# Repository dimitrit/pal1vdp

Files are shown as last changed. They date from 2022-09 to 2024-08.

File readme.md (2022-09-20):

# PAL-1 Sprite Colour Graphics Adapter

The PAL-1 Sprite Colour Graphics Adapter is an expansion board for the PAL-1 system<sup>1</sup>, 
based on the Texas Instruments TMS9918A Video Display Processor (VDP)<sup>2</sup> and was inspired 
by a Ciarcia's Circuit Cellar project<sup>3</sup>. 

The TMS9918A VDP was used in video systems to provide data display on raster scanned colour
television sets or monitors. The IC generates all necessary video, control, and synchronisation
signals and also controls the storage and retrieval of display data in its own dedicated screen 
memory. 

> **Note**  
> The TMS9918A VDP generates a 525-line NTSC encoded colour video signal. While the TMS9928A
> VDP, which is intended for use with PAL video systems, is functionally compatible with the
> TMS9918A, it is not pin-for-pin compatible. Thus it is **not possible** to use the TMS9928A 
> VDP in the PAL-1 Sprite Colour Graphics Adapter. Instead, users who do not have access to an 
> NTSC TV or monitor are recommended to use AV to HDMI or AV to VGA converters as appropriate.
> Such converters are widely available from the usual e-commerce and auction web sites. 

## Acknowledgements
The SRAM circuitry is based on work by Tom LeMense and Dan Werner<sup>4,5</sup>.  
PAL-1 and the PAL-1 logo used with kind permission of Liu Ganning.

## References
1. Liu Ganning, ‘PAL-1 Microcomputer User Manual’, 2020 <http://pal.aibs.ws/assets/PAL_en.pdf> [accessed 21 July 2022].
2. ‘9900 TMS9918A/TMS9928A/TMS9929A Video Display Processors’ (Texas Instruments Incorporated, 1982) <https://web.archive.org/web/20180717212934/https://emu-docs.org/VDP%20TMS9918/Datasheets/TMS9918.pdf> [accessed 17 September 2022].
3. Steve Ciarcia, ‘High-Resolution Sprite-Oriented Color Graphics’, Byte, 7.8 (1982), 57–80.
4. Tom LeMense, ‘SRAM Replacement for TMS99x8 VRAM’, 2010 <https://retrobrewcomputers.org/n8vem-pbwiki-archive/0/35845334/48860720/33053543/SRAM%20Replacement%20for%20TMS99x8%20VRAM.pdf> [accessed 17 September 2022].
5. Tom LeMense and Dan Werner, ‘Video Display Interface Board’, RetroBrew Computers Wiki, 2021 <https://www.retrobrewcomputers.org/doku.php?id=boards:ecb:scg:start> [accessed 17 September 2022].

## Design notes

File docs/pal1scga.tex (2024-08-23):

\documentclass[a4paper,11pt,twoside,openright]{report}
\usepackage{standalone}
\usepackage[lmargin=142pt,rmargin=95pt,tmargin=127pt,bmargin=123pt]{geometry}
\usepackage[titleformat=italic,commabeforerest,citefull=first,oxford,super,dotafter=bibentry,see,bibformat=ibidem,human]{jurabib}
\usepackage{csvsimple}
\usepackage{graphicx}
\usepackage{caption}
\usepackage{subcaption}
\usepackage[table]{xcolor}
\usepackage[online,flushleft]{threeparttable}
\usepackage{multirow}
\usepackage{makecell}
\usepackage[super]{nth}
\usepackage[most]{tcolorbox}
\usepackage{listings}
\usepackage{float}
\usepackage{enumitem}
\usepackage{fdsymbol}
\usepackage{awesomebox}
\usepackage{titlesec}
\usepackage[hidelinks]{hyperref}
%\usepackage{inconsolata}
\usepackage{tikz}
\usepackage{tkz-euclide}
\usetikzlibrary{intersections,shapes.arrows,arrows.meta}
\lstset{aboveskip=18pt,belowskip=18pt}
\tcbset{colframe=blue!50!black,colback=blue!20}
\hypersetup{
%   colorlinks=false,
%    linkcolor=blue,
%    filecolor=magenta,
%    urlcolor=cyan,
    pdftitle={PAL-1 Sprite Colour Graphics Adapter},
    pdfpagemode=UseThumbs,
    pdfauthor={Plastic Objects Limited}
}
\renewcommand{\arraystretch}{1.1}
\renewcommand*{\biburlprefix}{\jblangle{}}
\renewcommand*{\bibbudcsep}{~}
\renewcommand\bibname{References}
\AddTo\bibsenglish{\renewcommand*{\urldatecomment}{accessed }}
\titleformat{\chapter}{\normalfont\huge}{\thechapter.}{20pt}{\huge\it}
\makeatletter
\newcommand{\code}{\texttt}
\newcommand\frontmatter{
  \cleardoublepage
  \pagenumbering{roman}}
\newcommand\mainmatter{
  \cleardoublepage
  \pagenumbering{arabic}}
\newcommand\encircle[1]{
  \tikz[baseline=(X.base)]
  \node (X) [draw, shape=circle, inner sep=0] {\strut #1};}
\title{PAL-1 Sprite Colour Graphics Adapter}
\author{Plastic Objects Limited}
\date{}
\begin{document}
\frontmatter
\begin{titlepage}
\begin{figure}[t]
\centering
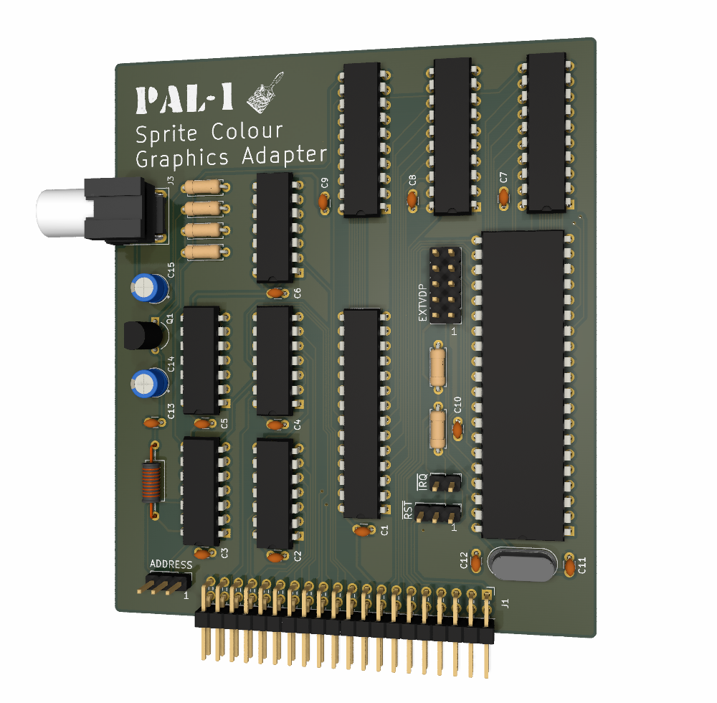
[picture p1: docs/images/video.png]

\end{figure}
\maketitle
\end{titlepage}
\clearpage
\noindent Published by \textbf{Plastic Objects Limited} \\
Beccles, UK

\bigskip
\noindent September 2024
\vfill
{\noindent\Large\textbf{Disclaimer}}
\vskip 6pt
Every effort has been made to ensure the accuracy of the information contained in this document. The information presented within is accurate at the time of publication. Whilst every effort is made to provide accurate information, no warranty or fitness is provided or implied, and the authors and publishers shall have neither liability nor responsibility to any person or entity with respect to any loss or damages arising from its use.

All trademarks, logos and brand names are the property of their respective owners. All company, product and service names mentioned in this document are for identification purposes only. Use of these names, trademarks and brands does not imply endorsement.

\thanks{PAL-1 and the PAL-1 logo used with kind permission by Liu Ganning.}
\clearpage
\tableofcontents
\listoffigures
\cleardoublepage
\chapter*{Introduction}
\addcontentsline{toc}{chapter}{Introduction}
The PAL-1 Sprite Colour Graphics Adapter (SCGA) is an expansion module for the PAL\nobreakdash-1 system\cite{ganning1} based on the Texas Instruments TMS9918A Video Display Processor (VDP)\cite{texas1}. The TMS9918A VDP was used in video systems to provide data display on raster scanned colour television sets or monitors. The IC generates all necessary video, control, and synchronisation signals and also controls the storage and retrieval of display data in its own dedicated screen memory.

\awesomebox[blue]{2pt}{\faInfoCircle}{blue}{The TMS9918A VDP generates a 525-line NTSC encoded colour video signal. While the TMS9928A VDP, which is intended for use with PAL video systems, is functionally compatible with the TMS9918A, it is not pin-for-pin compatible. Thus it is not possible to use the TMS9928A VDP in the PAL-1 Sprite Colour Graphics Adapter. Instead, users who do not have access to an NTSC TV or monitor are recommended to use AV to HDMI or AV to VGA converters as appropriate. Such converters are widely available from the usual e-commerce and auction web sites.}

This expansion module was inspired by a Ciarcia's Circuit Cellar project for a `High-Resolution Sprite-Oriented Color Graphics' expansion card for the Apple II computer, published in BYTE magazine.\cite[pp. 57--80]{byte1} The design for the PAL-1 SCGA also incorporates Static RAM (SRAM) circuitry based on work by Tom LeMense and Dan Werner.\cite{lemense1}\textsuperscript{,}\cite{werner1}

\section*{Overview of the TMS9918A VDP}
The TMS9918A VDP contains all necessary circuitry to generate a video display with up to 16 colours and a maximum resolution of 256 x 192 pixels. Additionally, the VDP supports the display of up to 32 sprites. The image displayed on the screen can best be envisioned as a number of display planes sandwiched together, where each plane has a different priority. For an entity on a specific plane to show through, all planes with higher priorities must be transparent at that point (see Figure \ref{fig:planes}).

\begin{figure}[h!]
	\centering
    \begin{subfigure}[b]{0.4\textwidth}
		\centering
			\scalebox{0.1}{
			\begin{tikzpicture}[font=\sffamily]
				\foreach \p [
				count=\q,
				evaluate=\q as \r using 9-\q
				] in {0,1,2,31,{Pattern plane (text \& graphics)},{Backdrop (solid colour)},{External VDP input},{Black plane}} {
					\def\c{white}
					\ifnumequal{\q}{1}{\def\c{black}}{}
					\ifnumequal{\q}{3}{\def\c{gray!40}}{}
					\draw [line width=4,fill=\c] (\r*6+2.25,\r*5+5) rectangle ++(16,12);
					\draw (\q*6+18.5, \q*5+6) node[anchor=west,scale=8]{\p};
				}
				\foreach \q in {1,2,3} {
					\draw[fill=black] (\q*1.75+38.5,\q+20.5) circle (.25);
				}
				\draw (34,39) node[anchor=west,scale=6]{Hello world};
				\draw[fill=gray!30,line width=2] (9,11) -- ++(4,0) -- ++(-2,4) -- cycle;
				\begin{scope}[fill=white]
					\fill[clip] (24.25,18) rectangle ++(4,4);
					\draw[line width=2] (25.25,20) circle (2);
				\end{scope}
				\draw[fill=gray!80,line width=2] (31.25,21) rectangle ++(4,4);
				\draw [decorate,decoration={brace,amplitude=26pt,mirror,raise=8ex},line width=4]
				(46,10) -- ++(0,18) node[midway,xshift=30em,scale=8]{Sprite planes};

			\end{tikzpicture}
		}
		\caption{Individual display planes.}
	\end{subfigure}\hfill
    \begin{subfigure}[b]{0.4\textwidth}
		\centering
		\scalebox{0.1}{
			\begin{tikzpicture}[font=\sffamily]
				\draw[line width=4] (-12,60) -- ++(-8,-12) -- ++(-4,8);
				\draw[fill=black!80] (-20,43) circle (6);
				\draw[line width=4,fill=white,rounded corners=0.2cm] (-32,28) rectangle ++(28,20) {};
				\draw[line width=8,rounded corners=1cm,fill=gray!40] (-30,30) rectangle ++(20, 16) {};
				\draw[fill=black] (-12.1,59.9) circle (.3);
				\draw[fill=black] (-24,56) circle (.3);
				\draw[fill=black!60,line width=4] (-7,41) circle (1);
				\draw[fill=black!60,line width=4] (-7,44) circle (1);
				\begin{scope}
					\draw[clip] (-7,41) circle (1);
					\draw[line width=8] (-7.5,40) -- (-6.5,42);
				\end{scope}
				\begin{scope}
					\draw[clip] (-7,44) circle (1);
					\draw[line width=8] (-6.8,43) -- (-7.2,45);
				\end{scope}
				\draw[fill=black!60,line width=2] (-9,31) rectangle ++(4,6);
				\foreach \q in {1, ..., 5}{
					\draw[line width=8, color=black!40] (-8.5,\q+31) -- ++(3,0);
				}
				\draw [color=white,fill=white] (-28,32) rectangle ++(16,12);
				\draw (-26,41) node[anchor=west,scale=6]{Hello world};
				\draw[fill=gray!30,line width=2] (-27,33) -- ++(4,0) -- ++(-2,4) -- cycle;
				\draw[fill=gray!80,line width=2] (-17,33) rectangle ++(4,4);
				\draw[fill=white,line width=2] (-17,37) circle (2);

				\draw[line width=2] (-17,30.5) -- ++(3,-5) -- ++(-1,0) -- ++(3,-5)
				node[scale=8,yshift=-.6em]{Backdrop};
			\end{tikzpicture}
		}
		\caption{Image shown on screen.}
	\end{subfigure}
    \caption[TMS9918A VDP display planes]{TMS9918A VDP overlapping display planes.}
	\label{fig:planes}
\end{figure}

In descending priority order, the display planes are made up of 32 \textit{Sprite Planes}, each of which may contain a single sprite. Below these sprite planes is the \textit{Pattern Plane}, which is used for the display of textual and graphics images. Below this is the \textit{Backdrop Plane}, which provides a single colour border around all other planes and sets the default colour for the active display area. Finally, with the lowest priority is the \textit{External Video Plane}, which displays a video image from a compatible external source (see also appendix \ref{sec:ttlpins}).

The VDP supports four video colour display modes that determine the appearance of the Pattern Plane. In both graphics modes, \textit{Graphics 1} and \textit{Graphics 2}, the pattern plane is split into groups of 8x8 pixels, referred to as pattern positions. Graphics and images using multiple colours may be created by defining unique patterns for each pattern position. In \textit{Text} mode, the Pattern Plane is split into groups of 6x8 pixels, resulting in 40x24 text positions on the screen. Sprites are not displayed in \textit{Text} mode and only two colours are allowed. Finally, in \textit{Multicolor} mode, the screen is split into a grid of 64x48 positions, each of which is 4x4 pixels. In this mode, each position may have a unique colour.

The \textit{Sprite Planes} are used for the display of up to 32 sprites in the \textit{Multicolor} and \textit{Graphics} modes. Sprites are automatically transparent in \textit{Text} mode and thus cannot be used in this mode. Each sprite covers a 8x8, 16x16 or 32x32 pixel area and may be positioned anywhere on its plane. Any part of the plane not covered by the sprite is transparent, as may be all or part of a sprite.

The VDP registers define the base addresses for several sub-blocks within Video RAM (VRAM). The sub-blocks form \textit{tables} which are used to define sprites and produce the desired text or images on the screen. Before use, the contents of these tables must be initialised by applications running on the PAL-1. Displaying text, drawing images and moving sprites across the screen can be achieved by choosing the relevant register parameters and changing the pointers.

\mainmatter
\chapter{Getting Started}
\section*{Board assembly}
Before assembling your PAL-1 Sprite Colour Graphics Adapter board check the package contents against the Bill of Materials on page \pageref{sec:bom}, and contact your distributor as soon as possible if any items are missing.

No specialist tools are required for assembling the board, though care must be taken when handling ESD sensitive components, especially the ICs. Before inserting the ICs into their sockets, check the board for dry joints and solder bridges. Also be sure to pay special attention to the orientation of the ICs, ensuring pin 1 of each IC is correctly aligned. Refer to the board layout on page \pageref{fig:layout} for the orientation of ICs, diodes and electrolytic capacitors.

\section*{Installation and configuration}
\label{sec:configuration}

Because of its width, the PAL-1 Sprite Colour Graphics Adapter cannot be installed in all slots of the PAL-1 Motherboard.\cite{ganning2} Rather, it must be installed in any of slots 4, 5, or 6. Alternatively, it may be directly connected to the PAL-1 using a 40-pin IDC cable.

\awesomebox[red]{2pt}{\faHandPaper}{red}{To prevent damage to your system, \textit{always} power off your PAL-1 before installing or removing the PAL-1 Sprite Colour Graphics Adapter board. Ensure that the pins are correctly aligned when inserting the board into the PAL-1 motherboard or when directly connecting it to the PAL-1 expansion port using an IDC cable.}

\subsection*{Data and register addresses}
The TMS9918A VDP has an 8-bit data bus, which is memory mapped on the PAL-1 system at addresses determined by the position of the \textsf{ADDRESS} jumper, as shown in Table \ref{tab:address}. Up to two PAL-1 Sprite Colour Graphics Adapters can be installed in one system by assigning each adapter unique data and register addresses.

\begin{table}
	\centering
	\sf
	\renewcommand{\arraystretch}{1.1}
	\begin{tabular}{@{\extracolsep{4pt}}ccc@{}}
		\hline
		\textbf{Pins} & \textbf{VDP data} & \textbf{VDP register} \\
		\hline
		\textbf{1 -- 2} & \$16EC & \$16ED \\
		\textbf{2 -- 3} & \$16EE & \$16EF \\
		\hline
	\end{tabular}
	\caption{\textsf{ADDRESS} jumper settings.}
	\label{tab:address}
\end{table}
\subsection*{Option jumpers}
The PAL-1 Sprite Colour Graphics Adapter has two option jumpers to configure its behaviour:

\begin{itemize}
	\item[$\overline{\mbox{RST}}$]
	\begin{description}
		\item[1 -- 2] Disables TMS9918A $\overline{\mbox{RESET}}$/SYNC using pull-up resistor $R1$.
		\item[2 -- 3] Connects the TMS9918A  $\overline{\mbox{RESET}}$/SYNC line with the $\overline{\mbox{RESET}}$ line of the PAL-1 MOS6502 CPU, ensuring it is used as a reset signal on the VDP.
		\item[No jumper] This jumper \textit{must} be removed when using the \textsf{EXTVDP} external video pin header.
	\end{description}
	\item[$\overline{\mbox{INT}}$] Enable CPU interrupts. If enabled, interrupts are raised each time a frame is completed, while the beam is tracing up to the upper left corner of the screen. This occurs every $1/60$\textsuperscript{th} of a second (approximately).
\end{itemize}

\chapter{Sample Code}

Programming the PAL-1 Sprite Colour Graphics Adapter simply requires the ability to write to and read from the memory mapped data and register addresses. Many programming languages provide statements to achieve this, including the \code{POKE} and \code{PEEK} statements in BASIC, and \code{C!} and \code{C@} in Forth.

Note that the examples included below use the default SCGA data and register addresses (\$16EC, $5868_{10}$ and \$16ED, $5869_{10}$).  Further examples may be found on Github at \url{https://github.com/dimitrit/pal1vdp}.

\subsection*{BASIC}

\textsf{TODO!}

%\lstinputlisting[basicstyle=\footnotesize\ttfamily,caption={BASIC example},captionpos=b,
%	language={[Visual]Basic},label={lst:sample1},frame=single]{../src/KNIGHT.BAS}

\subsection*{6502 assembly language}

The assembly language example is taken from the `\textit{High-Resolution Sprite-Oriented Color Graphics}' article in the August 1982 issue of BYTE magazine.\cite[pp. 57--80]{byte1} The code has been modified where required to allow it to run on the PAL-1.

\begin{figure}[h!]
\centering
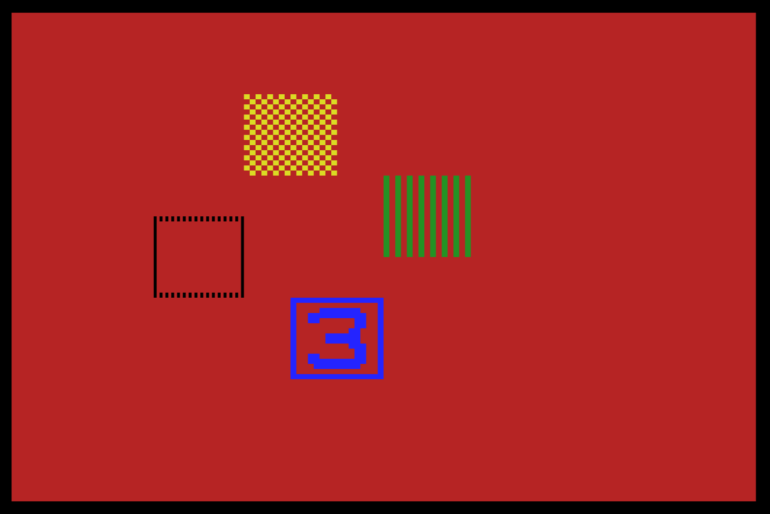
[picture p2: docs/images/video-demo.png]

\caption[Assembly language Video Demo showing sprites]{6502 Assembly language \textit{Video Demo} showing four sprites.}
\label{fig:asmdemo}
\end{figure}

The program starts by initialising the eight VDP registers and clearing the VRAM. In this example the 9918A is set to the following operating specifications: Graphics II mode, external video input disabled, and 16 x 16 pixel sprites, with selectable magnification to twice their normal size (32 x 32 pixels) under keyboard control. When the program starts, four different sprites are displayed, as shown in Figure \ref{fig:asmdemo}. The display can be changed as follows. When you press the \textsf{GO} key, the sprites' position coordinates are incremented and the sprites move. Pressing the \textsf{0} key and then a hexadecimal digit \textsf{1} through \textsf{F} will set one of the fifteen background colours or transparency. Pressing the \textsf{AD} or \textsf{DA} keys will vary the size of the sprites between 16 x 16 and 32 x 32 pixels.

\lstinputlisting[basicstyle=\footnotesize\ttfamily,caption={Ciarcia's Circuit Cellar Video Demo},
	captionpos=b,language={[Motorola68k]Assembler},
	label={lst:sample2},frame=single]{../src/ciarcia.a65}

\appendix

\chapter{Connector Pin Outs}
\label{sec:connectors}

\subsection*{External Video Pin Header (\textsf{EXTVDP})}
\label{sec:ttlpins}
The PAL-1 Sprite Colour Graphics Adapter (SCGA) external video pin header (\textsf{EXTVDP}) can be used to connect a compatible external video source. Alternatively, it allows the SCGA to be used as the source for other systems.\cite[pp. 3.7--3.8]{texas1}

Note that the pins of this header are numbered `odd-even' with pin \textsf{1} clearly marked on the PCB, as shown in figures \ref{fig:pinheader} and \ref{fig:layout}. \textbf{Be sure to check the TTL voltage levels and signals before connecting any external systems as incorrect voltages and/or incompatible signals may result in permanent damage to your PAL-1 Sprite Colour Graphics Adapter.}

\begin{figure}[h!]
	\centering
    \begin{minipage}[b]{\linewidth}
	    \centering
		\scalebox{0.1}{
			\begin{tikzpicture}[font=\sffamily]
				\draw (3,5.5) node[scale=12, rotate=-90,color=gray]{1};
				\draw (5.5,17) node[scale=12,anchor=west,color=gray]{EXTVDP};
				\draw [line width=8] (6,4) -- ++(0,9);
				\draw [line width=8] (6,13)
				\foreach \q in {1, ..., 5} { -- ++(1,1) -- ++(4,0) -- ++(1,-1) } -- ++(0,-9)
				\foreach \q in {5, ..., 1} {	-- ++(-1,-1) -- ++(-4,0) -- ++(-1,1) } -- cycle;
				\foreach \q [
						evaluate=\q as \odd using int(\q*2-1),
						evaluate=\q as \even using int(\q*2)
				] in {5, ..., 1} {
					\draw [fill=black] (\q*6+2.25,5.5) rectangle ++(1.5,1.5);
					\draw [fill=black] (\q*6+2.25,10) rectangle ++(1.5,1.5);

					\draw (3+\q*6, 16.5) node[scale=8]{\even};
					\draw (3+\q*6, 0.5) node[scale=8]{\odd};
				}
			\end{tikzpicture}
		}
		\captionof{figure}[External video pin header]{\textsf{EXTVDP} external video pin header.}
		\label{fig:pinheader}
	\end{minipage}
	~\par\bigskip
    \begin{minipage}[b]{\linewidth}
			\renewcommand{\arraystretch}{1.1}
			\centering
			\begin{tabular}{@{\extracolsep{4pt}}clp{80mm}@{}}
				\hline
				Pin & Signal & Description \\
				\cline{1-3}
				1 & GND & Ground  \\
				2 & VCC & +5V Supply Voltage \\
				3 & GND & Ground  \\
				4 & COMVID & Composite Video Output \\
				5 & GROMCLK & VDP Output Clock $= XTAL/24$ \\
				6 & COMVID & Composite Video Output \\
				7 & EXTVDP & External Video (VDP) Input \\
				8 & CPUCLK &  VDP Colour Burst Frequency Clock \\
				9 &  $\overline{\mbox{RESET}}$/SYNC & This is a tri-level input pin. When it is below 0.8 volts, $\overline{\mbox{RESET}}$/SYNC initialises the VDP. When it is above 9 volts $\overline{\mbox{RESET}}$/SYNC is the synchronising input for external video. \\
				10 & COMVID\textsubscript{r} & Unconditioned Composite Video Output of the TMS9918A VDP. \\
				\hline
			\end{tabular}

		\captionof{table}[External video pin header]{\textsf{EXTVDP} external video pin header.}
		\label{tab:ttlpins}
	\end{minipage}
\end{figure}

\chapter{Schematic}
\label{sec:schematic}

\begin{figure}[h!]
	\centering
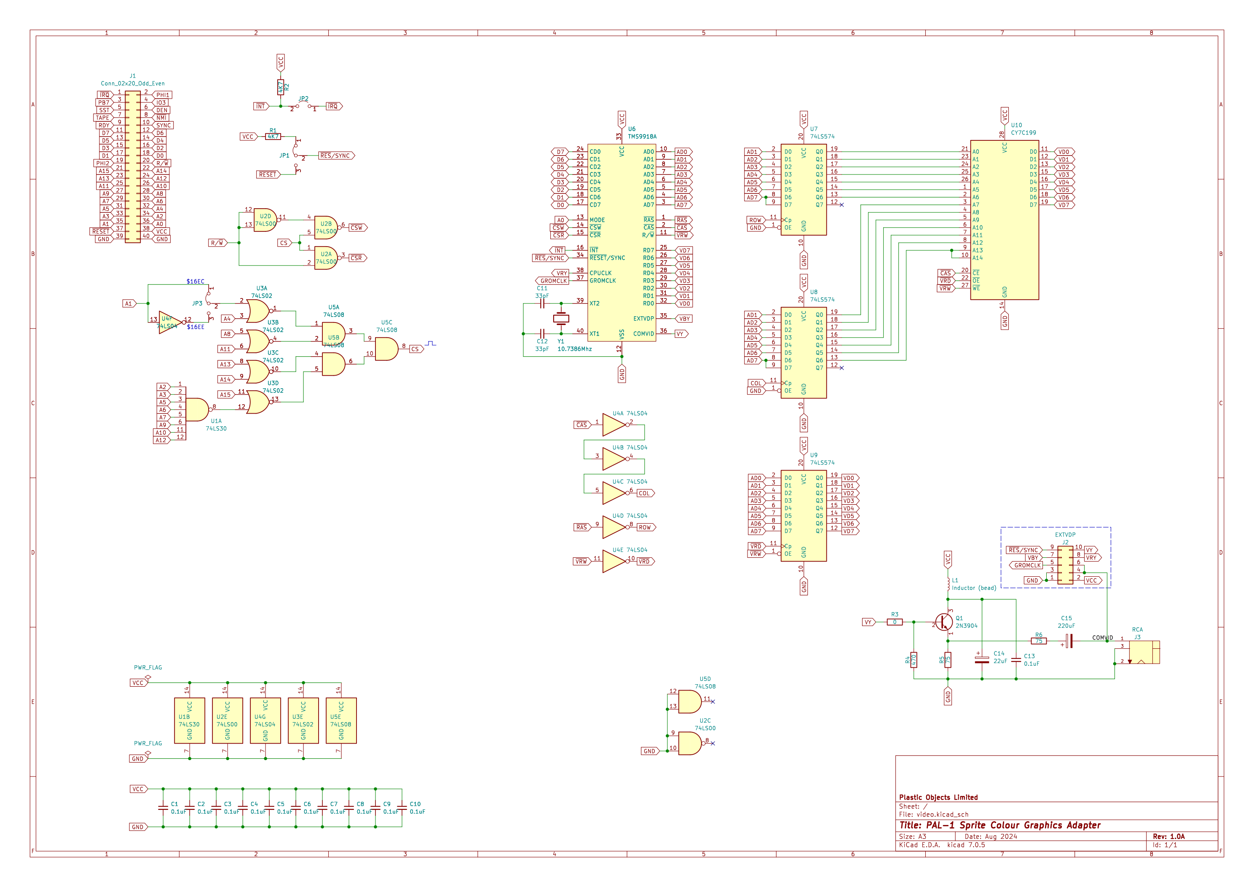
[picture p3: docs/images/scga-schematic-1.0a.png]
	
	\caption[Sprite Colour Graphics Adapter schematic]{PAL-1 Sprite Colour Graphics Adapter schematic.}
	\label{fig:layout}
\end{figure}

\chapter{Board layout}
\begin{figure}[h!]
\centering
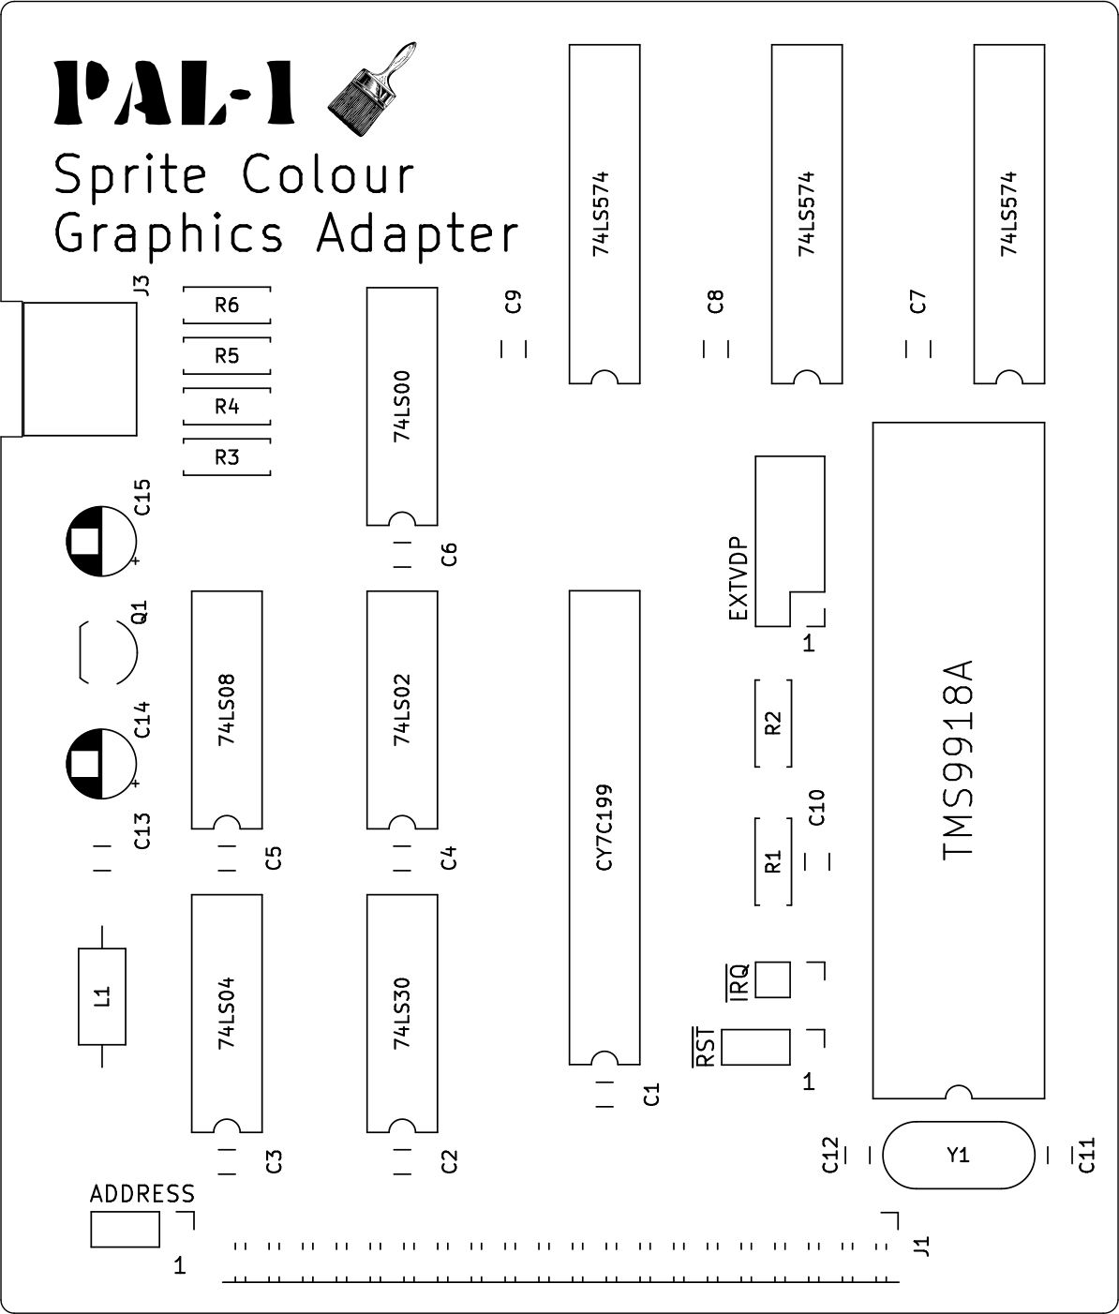
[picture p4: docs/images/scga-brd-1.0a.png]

\caption[Sprite Colour Graphics Adapter component locations]{PAL-1 Sprite Colour Graphics Adapter component locations.}
\label{fig:layout}
\end{figure}

\chapter{Bill of Materials}
\label{sec:bom}

\begin{table}[htb]
	\csvreader[head to column names,
	separator=semicolon,
	tabular={| c | c | c | p{7cm} |},
	table head=\hline\rowcolor{gray!20}\textbf{Part} & \textbf{Qty} & \textbf{Value} & \textbf{Description}\\\hline,
	late after last line=\\\hline]{scga-bom-1.0a.csv}{}
	{\Ref&\Qnty&\Value&\Description}
	\caption[Sprite Colour Graphics Adapter bill of materials]{PAL-1 Sprite Colour Graphics Adapter v1.0A bill of materials.}
	\label{tab:bom}
\end{table}

\bibliography{scga}
\bibliographystyle{jox}
\addcontentsline{toc}{chapter}{References}

\end{document}

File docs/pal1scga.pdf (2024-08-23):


## PAL-1 Sprite Colour Graphics Adapter

Plastic Objects Limited

Published by Plastic Objects Limited Beccles, UK

September 2024

## Disclaimer

Every effort has been made to ensure the accuracy of the information contained in this document. The information presented within is accurate at the time of publication. Whilst every effort is made to provide accurate information, no warranty or fitness is provided or implied, and the authors and publishers shall have neither liability nor responsibility to any person or entity with respect to any loss or damages arising from its use.
All trademarks, logos and brand names are the property of their respective owners. All company, product and service names mentioned in this document are for identification purposes only. Use of these names, trademarks and brands does not imply endorsement.
PAL-1 and the PAL-1 logo used with kind permission by Liu Ganning.

ii

# Contents

Introduction | vii
1 Getting Started | 1
2 Sample Code | 3
A Connector Pin Outs | 9
B Schematic | 11
C Board layout | 13
D Bill of Materials | 15
References | 17

iii

iv

# List of Figures

1 | TMS9918A VDP display planes | viii
2.1 Assembly language Video Demo showing sprites | | 4
A.1 External video pin header | 10
B.1 Sprite Colour Graphics Adapter schematic | 12
C.1 Sprite Colour Graphics Adapter component locations | 13

v

vi

# Introduction

The PAL-1 Sprite Colour Graphics Adapter (SCGA) is an expansion module for the PAL-1 system¹
based on the Texas Instruments TMS9918A Video Display Processor (VDP)²
. The TMS9918A VDP was used in video systems to provide data display on raster scanned colour television sets or monitors. The IC generates all necessary video, control, and synchronisation signals and also controls the storage and retrieval of display data in its own dedicated screen memory.
ò

The TMS9918A VDP generates a 525-line NTSC encoded colour video signal. While the TMS9928A VDP, which is intended for use with PAL video systems, is functionally compatible with the TMS9918A, it is not pin-for-pin compatible. Thus it is not possible to use the TMS9928A VDP in the PAL-1 Sprite Colour Graphics Adapter. Instead, users who do not have access to an NTSC TV or monitor are recommended to use AV to HDMI or AV to VGA converters as appropriate. Such converters are widely available from the usual e-commerce and auction web sites.

This expansion module was inspired by a Ciarcia’s Circuit Cellar project for a ‘High-Resolution Sprite-Oriented Color Graphics’ expansion card for the Apple II computer, published in BYTE magazine.³ The design for the PAL-1 SCGA also incorporates Static RAM (SRAM) circuitry based on work by Tom LeMense and Dan Werner.⁴,5

1
Liu Ganning, ‘PAL-1 Microcomputer User Manual’ (November 2020), http://pal.aibs.ws/assets/PAL_en.pdf (http://pal.aibs.ws/assets/PAL_en.pdf) accessed 2024-08-18.
2Texas Instruments, ‘TMS9918A/TMS9928A/TMS9929A Video Display Processors’ (1982).

3
Steve Ciarcia, ‘High-Resolution Sprite-Oriented Color Graphics’ (August 1982), pp. 57–80.
4Tom LeMense, ‘SRAM Replacement for TMS99x8 VRAM’, Technical report (January 2010), https://retrobrewcomputers.org/n8vem-pbwiki-archive/0/35845334/48860720/33053543/SRAM%20Replacement%20for%20TMS99x8%20VRAM.pdf (https://retrobrewcomputers.org/n8vem-pbwiki-archive/0/35845334/48860720/33053543/SRAM%20Replacement%20for%20TMS99x8%20VRAM.pdf) accessed 2024-08-18.
5Dan Werner, ‘Video Display Interface Board’, https://www.retrobrewcomputers.org/doku.php?id=boards:ecb:scg:start (https://www.retrobrewcomputers.org/doku.php?id=boards:ecb:scg:start) accessed 2024-08-18.

vii

## Overview of the TMS9918A VDP

The TMS9918A VDP contains all necessary circuitry to generate a video display with up to 16 colours and a maximum resolution of 256 x 192 pixels. Additionally, the VDP supports the display of up to 32 sprites. The image displayed on the screen can best be envisioned as a number of display planes sandwiched together, where each plane has a different priority. For an entity on a specific plane to show through, all planes with higher priorities must be transparent at that point (see Figure 1).

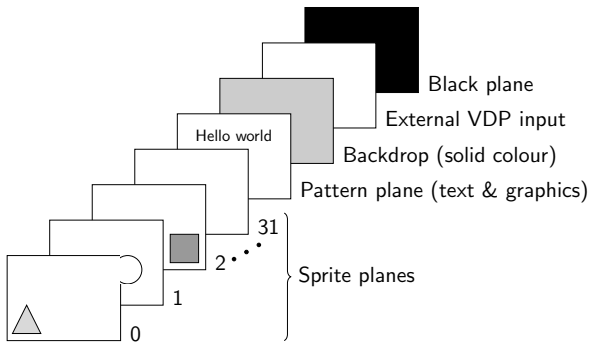
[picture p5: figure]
Pattern plane (text & graphics); Backdrop (solid colour); External VDP input; Black plane; Hello world; Sprite planes

(a) Individual display planes.

Hello world

Backdrop

(b) Image shown on screen.

Figure 1: TMS9918A VDP overlapping display planes.

In descending priority order, the display planes are made up of 32 Sprite Planes, each of which may contain a single sprite. Below these sprite planes is the Pattern Plane, which is used for the display of textual and graphics images. Below this is the Backdrop Plane, which provides a single colour border around all other planes and sets the default colour for the active display area. Finally, with the lowest priority is the External Video Plane, which displays a video image from a compatible external source (see also appendix A).
The VDP supports four video colour display modes that determine the appearance of the Pattern Plane. In both graphics modes, Graphics 1 and Graphics 2, the pattern plane is split into groups of 8x8 pixels, referred to as pattern positions. Graphics and images using multiple colours may be created by defining unique patterns for each pattern position. In Text mode, the Pattern Plane is split into groups of 6x8 pixels, resulting in 40x24 text positions on the screen. Sprites are not displayed in Text mode and only two colours are allowed. Finally, in Multicolor mode, the screen is split into a grid of 64x48 positions, each of which is 4x4 pixels. In this mode, each position may have a unique colour.
The Sprite Planes are used for the display of up to 32 sprites in the Multicolor and Graphics modes. Sprites are automatically transparent in

viii

Text mode and thus cannot be used in this mode. Each sprite covers a 8x8, 16x16 or 32x32 pixel area and may be positioned anywhere on its plane. Any part of the plane not covered by the sprite is transparent, as may be all or part of a sprite.
The VDP registers define the base addresses for several sub-blocks within Video RAM (VRAM). The sub-blocks form tables which are used to define sprites and produce the desired text or images on the screen. Before use, the contents of these tables must be initialised by applications running on the PAL-1. Displaying text, drawing images and moving sprites across the screen can be achieved by choosing the relevant register parameters and changing the pointers.

ix

x

# 1. Getting Started

## Board assembly

Before assembling your PAL-1 Sprite Colour Graphics Adapter board check the package contents against the Bill of Materials on page 15, and contact your distributor as soon as possible if any items are missing.
No specialist tools are required for assembling the board, though care must be taken when handling ESD sensitive components, especially the ICs. Before inserting the ICs into their sockets, check the board for dry joints and solder bridges. Also be sure to pay special attention to the orientation of the ICs, ensuring pin 1 of each IC is correctly aligned. Refer to the board layout on page 13 for the orientation of ICs, diodes and electrolytic capacitors.

## Installation and configuration

Because of its width, the PAL-1 Sprite Colour Graphics Adapter cannot be installed in all slots of the PAL-1 Motherboard.¹ Rather, it must be installed

in any of slots 4, 5, or 6. Alternatively, it may be directly connected to the PAL-1 using a 40-pin IDC cable.
§

To prevent damage to your system, always power off your PAL-1 before installing or removing the PAL-1 Sprite Colour Graphics Adapter board. Ensure that the pins are correctly aligned when inserting the board into the PAL-1 motherboard or when directly connecting it to the PAL-1 expansion port using an IDC cable.

Data and register addresses

The TMS9918A VDP has an 8-bit data bus, which is memory mapped on the PAL-1 system at addresses determined by the position of the ADDRESS jumper, as shown in Table 1.1. Up to two PAL-1 Sprite Colour Graphics

1
Liu Ganning, ‘PAL-1 MOTHERBOARD’ (2021), http://pal.aibs.ws/assets/Motherboard_manual.pdf (http://pal.aibs.ws/assets/Motherboard_manual.pdf) accessed 2024-08-18.

1

Pins | VDP data | VDP register
1 – 2 | $16EC | $16ED
2 – 3 | $16EE | $16EF

Table 1.1: ADDRESS jumper settings.

Adapters can be installed in one system by assigning each adapter unique data and register addresses.

Option jumpers

The PAL-1 Sprite Colour Graphics Adapter has two option jumpers to configure its behaviour:

RST 1 – 2 Disables TMS9918A RESET/SYNC using pull-up resistor R1.

2 – 3 Connects the TMS9918A RESET/SYNC line with the RESET line of the PAL-1 MOS6502 CPU, ensuring it is used as a reset signal on the VDP.

No jumper This jumper must be removed when using the EXTVDP external video pin header.

INT Enable CPU interrupts. If enabled, interrupts are raised each time a frame is completed, while the beam is tracing up to the upper left corner of the screen. This occurs every 1©60th of a second (approximately).

2

# 2. Sample Code

Programming the PAL-1 Sprite Colour Graphics Adapter simply requires the ability to write to and read from the memory mapped data and register addresses. Many programming languages provide statements to achieve this, including the POKE and PEEK statements in BASIC, and C! and C@ in Forth. Note that the examples included below use the default SCGA data and register addresses ($16EC, 586810 and $16ED, 586910). Further examples may be found on Github at https://github.com/dimitrit/pal1vdp.

BASIC

TODO!

6502 assembly language

The assembly language example is taken from the ‘High-Resolution Sprite-Oriented Color Graphics’ article in the August 1982 issue of BYTE magazine.¹ The code has been modified where required to allow it to run on the

PAL-1.
The program starts by initialising the eight VDP registers and clearing the VRAM. In this example the 9918A is set to the following operating specifications: Graphics II mode, external video input disabled, and 16 x 16 pixel sprites, with selectable magnification to twice their normal size (32 x 32 pixels) under keyboard control. When the program starts, four different sprites are displayed, as shown in Figure 2.1. The display can be changed as follows. When you press the GO key, the sprites’ position coordinates are incremented and the sprites move. Pressing the 0 key and then a hexadecimal digit 1 through F will set one of the fifteen background colours or transparency. Pressing the AD or DA keys will vary the size of the sprites between 16 x 16 and 32 x 32 pixels.

;
; ********************************************************* ;

1Ciarcia, pp. 57–80.

3


Figure 2.1: 6502 Assembly language Video Demo showing four sprites.

; | | *** VIDEO DEMO ***
;
;
KBD | = $C000 | ; APPLE KEYBOARD DATA
KSTRB | = $C010 | ; KEYBOARD DATA CLEAR
VREG | = $C081 | ; VDP REGISTER
VDATA | = $C080 | ; VDP RAM
;
| * = $200 | ; PROGRAM STARTING ADDRESS
;
; **************** INITIALIZE VDG ************************* ;
| LDY #$87 | ; REGISTER SELECT
| LDX #$07 | ; INITIALIZE COUNTER
INIT1 | LDA ITAB , X | ; LOAD INIT TABLE
| JSR SREG | ; WRITE TO VDP
| DEY | ; DECREMENT REGISTER
| DEX | ; DECREMENT COUNTER
| BNE INIT1 | ; DONE ?
;
; ************** CLEAR ALL MEMORY ************************* ;
| LDY #$40 | ; BYTE2 ADDRESS SET UP
| LDA #$00 | ; BYTE1 ADDRESS SET UP
| JSR SREG | ; WRITE TO VDP
| LDX #$C0 | ; COUNTER HIGH BYTE

4

NEXF | LDY # $00 | ; COUNTER LOW BYTE
FILL | STA VDATA | ; WRITE TO VDP RAM
| INY | ; INCREMENT LOW COUNTER
| BNE FILL | ; LOW COUNTER FULL ?
| INX | ; INCREMENT HIGH COUNTER
| BNE NEXF | ; HIGH COUNTER FULL ?
;
; ******** LOAD SPRITE ATTRIBUTES ************************* ;
LOOP | LDY # $47 | ; BYTE2 AT 0700 HEX
| LDA #$00 | ; BYTE1 ADDRESS SET UP
| JSR SREG | ; WRITE TO VDP
| LDX #$00 | ; INITIALIZE COUNTER
NEXA | LDA ATAB , X | ; LOAD ATTRIBUTE
| STA VDATA | ; STORE TO VDP RAM
| INX | ; INCREMENT COUNTER
| TXA
| CMP #$10 | ; TEST COUNTER
| BNE NEXA | ; DONE ?
;
; ********** LOAD SPRITE PATTERNS ************************* ;
| LDY #$40 | ; BYTE2 AT 0000 HEX
| LDA #$00 | ; BYTE1 ADDRESS SET UP
| JSR SREG | ; WRITE TO VDP
| LDX #$00 | ; INITIALIZE COUNTER
NEXS | LDA PTAB , X | ; LOAD PATTERN BYTE
| STA VDATA | ; STORE TO VDP RAM
| INX | ; INCREMENT COUNTER
| TXA
| CMP #$80 | ; TEST COUNTER
| BNE NEXS | ; DONE ?
;
; ************* CHANGE BACKGROUND ************************* ;
CBACK | LDA KBD | ; TEST FOR
| CMP #$CF | ; " O " KEY INPUT
| BNE CSIZE | ; TO SET BACKGROUND COLOR
| JSR LOADN | ; READ KEYBOARD
| LDY #$87 | ; BYTE1 REGISTER 7
| JSR SREG | ; STORE TO VDP
;
; ******************* CHANGE SIZE ************************* ;
CSIZE | LDA KBD | ; TEST FOR LEFT ARROW
| CMP #$88 | ; MAGNIFICATION X 1
| BNE ONE
| LDA ITAB +1 | ; LOAD REGISTER 1
| AND #$FE | ; MASK 0 ON LSB
| LDY #$81 | ; BYTE1 REGISTER 1
| JSR SREG | ; STORE TO VDP
ONE | CMP #$95 | ; TEST FOR RIGHT ARROW
| BNE MOVE | ; MAGNIFICATION X 2
| LDA ITAB +1 | ; LOAD REGISTER 1

5

| ORA #$01 | ; MASK 1 ON LSB
| LDY #$81 | ; BYTE1 REGISTER 1
| JSR SREG | ; STORE TO VDP
;
; ****************** MOVE SPRITES ************************* ;
MOVE | LDA KBD | ; MOVE ?
| CMP #$CD | ; TEST FOR " M " KEY
| BNE JUMP
| INC ATAB | ; SPRITE0 UP
| DEC ATAB +1 | ; SPRITE0 LEFT
| INC ATAB +4 | ; SPRITE1 UP
| INC ATAB +5 | ; SPRITE1 RIGHT
| DEC ATAB +8 | ; SPRITE2 DOWN
| DEC ATAB +9 | ; SPRITE2 LEFT
| DEC ATAB +$C | ; SPRITE3 DOWN
| INC ATAB +$D | ; SPRITE3 RIGHT
JUMP | BIT KSTRB | ; CLEAR KEYBOARD
| JMP LOOP | ; JUMP TO START
;
;
; ********* STORE VIDEO REGISTERS ************************* ;
SREG | STA VREG | ; STORE BYTE1
| STY VREG | ; STORE BYTE2
| RTS | ; RETURN
;
; ************* LOAD KEYBOARD INPUT *********************** ;
LOADN | BIT KSTRB | ; CLEAR KEYBOARD
WAIT | BIT KBD | ; TEST KEYBOARD
| BPL WAIT | ; IS KEY PRESSED ?
| LDA KBD
| AND #$F0 | ; TEST IF NUMERICAL INPUT
| CMP #$C0
| BEQ LETER
| LDA KBD
| AND #$0F | ; MASK OFF HIGH NIBBLE
| RTS | ; RETURN
LETER | LDA KBD
| CLC
| ADC #$09 | ; CONVERT INPUT TO HEX VALUE
| AND #$0F | ; MASK OFF HIGH NIBBLE
| RTS | ; RETURN
;
; ************************ TABLES ***
;
ITAB | . BYT $02 ,$C2 ,$01 ,$80 | ; INITIALIZE TABLE
| . BYT $01 ,$0E ,$00 ,$01
;
ATAB | . BYT $40 ,$60 ,$00 ,$03 | ; SPRITE 0 ATTRIBUTE
| . BYT $60 ,$60 ,$04 ,$07 | ; SPRITE 1 ATTRIBUTE
| . BYT $40 ,$80 ,$08 ,$0B | ; SPRITE 2 ATTRIBUTE
| . BYT $60 ,$80 ,$0C ,$0F | ; SPRITE 3 ATTRIBUTE

6

;
PTAB | . WORD $FF80 ,$8080 ,$8080 , $8080 ; SPRITE 0 PATTERN
| . WORD $8080 ,$8080 ,$8080 , $80FF ; 16 X 16 PIXELS
| . WORD $FF01 ,$0101 ,$0101 , $0101 ; 32 BYTES / SPRITE
| . WORD $0101 ,$0101 ,$0101 , $01FF
;
| . WORD $FF80 ,$879F ,$9880 , $8083 ; SPRITE 1 PATTERN
| . WORD $8380 ,$8098 ,$9F8F , $80FF
| . WORD $FF01 ,$F1F9 ,$1919 , $31F1
| . WORD $F139 ,$1919 ,$F9F1 , $01FF
;
| . WORD $AA55 ,$AA55 ,$AA55 , $AA55 ; SPRITE 2 PATTERN
| . WORD $AA55 ,$AA55 ,$AA55 , $AA55
| . WORD $AA55 ,$AA55 ,$AA55 , $AA55
| . WORD $AA55 ,$AA55 ,$AA55 , $AA55
;
| . WORD $AAAA ,$AAAA ,$AAAA , $AAAA ; SPRITE 3 PATTERN
| . WORD $AAAA ,$AAAA ,$AAAA , $AAAA
| . WORD $AAAA ,$AAAA ,$AAAA , $AAAA
| . WORD $AAAA ,$AAAA ,$AAAA , $AAAA
;
| . END

Listing 2.1: Ciarcia’s Circuit Cellar Video Demo

7

8

# A. Connector Pin Outs

External Video Pin Header (EXTVDP)

The PAL-1 Sprite Colour Graphics Adapter (SCGA) external video pin header (EXTVDP) can be used to connect a compatible external video source. Alternatively, it allows the SCGA to be used as the source for other systems.¹

Note that the pins of this header are numbered ‘odd-even’ with pin 1 clearly marked on the PCB, as shown in figures A.1 and C.1. Be sure to check the TTL voltage levels and signals before connecting any external systems as incorrect voltages and/or incompatible signals may result in permanent damage to your PAL-1 Sprite Colour Graphics Adapter.

1Texas Instruments, pp. 3.7–3.8.

9

1

### EXTVDP 10

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
Figure A.1: EXTVDP external video pin header.

Pin | Signal | Description
1 | GND | Ground
2 | VCC | +5V Supply Voltage
3 | GND | Ground
4 | COMVID | Composite Video Output
5 | GROMCLK | VDP Output Clock XT AL©24
6 | COMVID | Composite Video Output
7 | EXTVDP | External Video (VDP) Input
8 | CPUCLK | VDP Colour Burst Frequency Clock
9 | RESET/SYNC | This is a tri-level input pin. When it is below 0.8 volts, RESET/SYNC initialises the VDP. When it is above 9 volts RESET/SYNC is the synchro-
| | nising input for external video.
10 | COMVIDr | Unconditioned Composite Video Output of the TMS9918A VDP.

Table A.1: EXTVDP external video pin header.

10

# B. Schematic

11

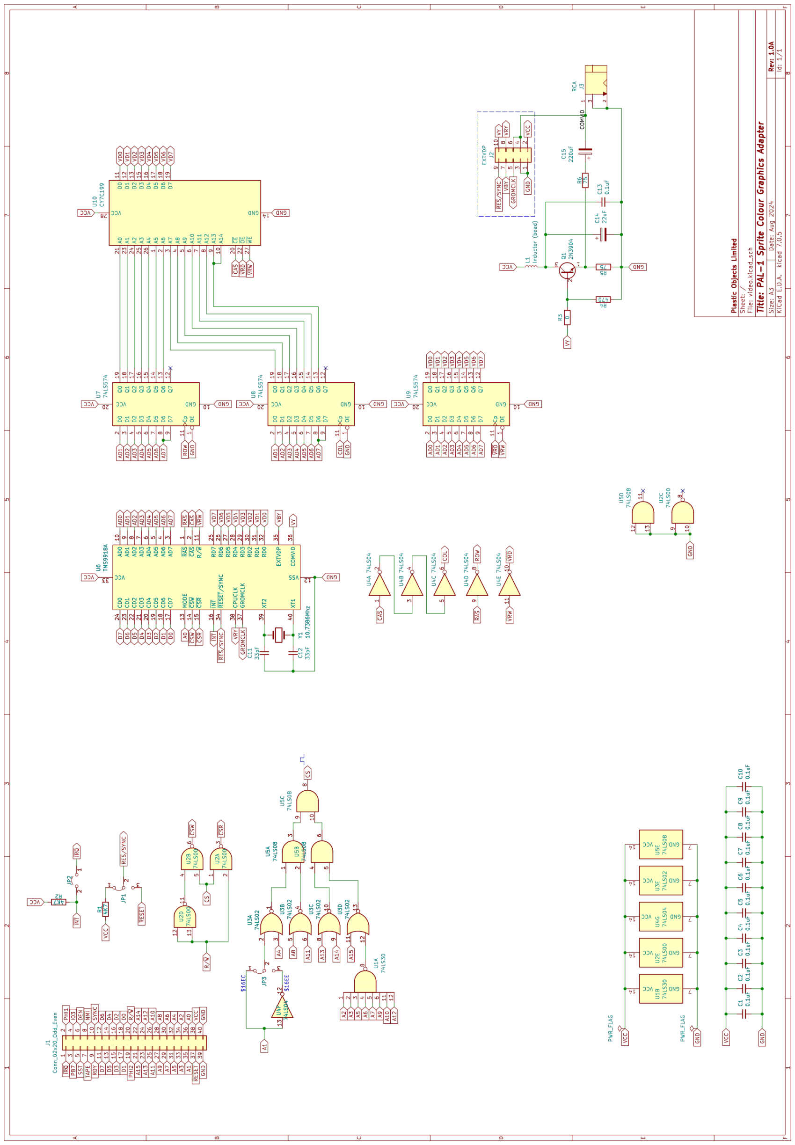
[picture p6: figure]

Figure B.1: PAL-1 Sprite Colour Graphics Adapter schematic.

12

# C. Board layout

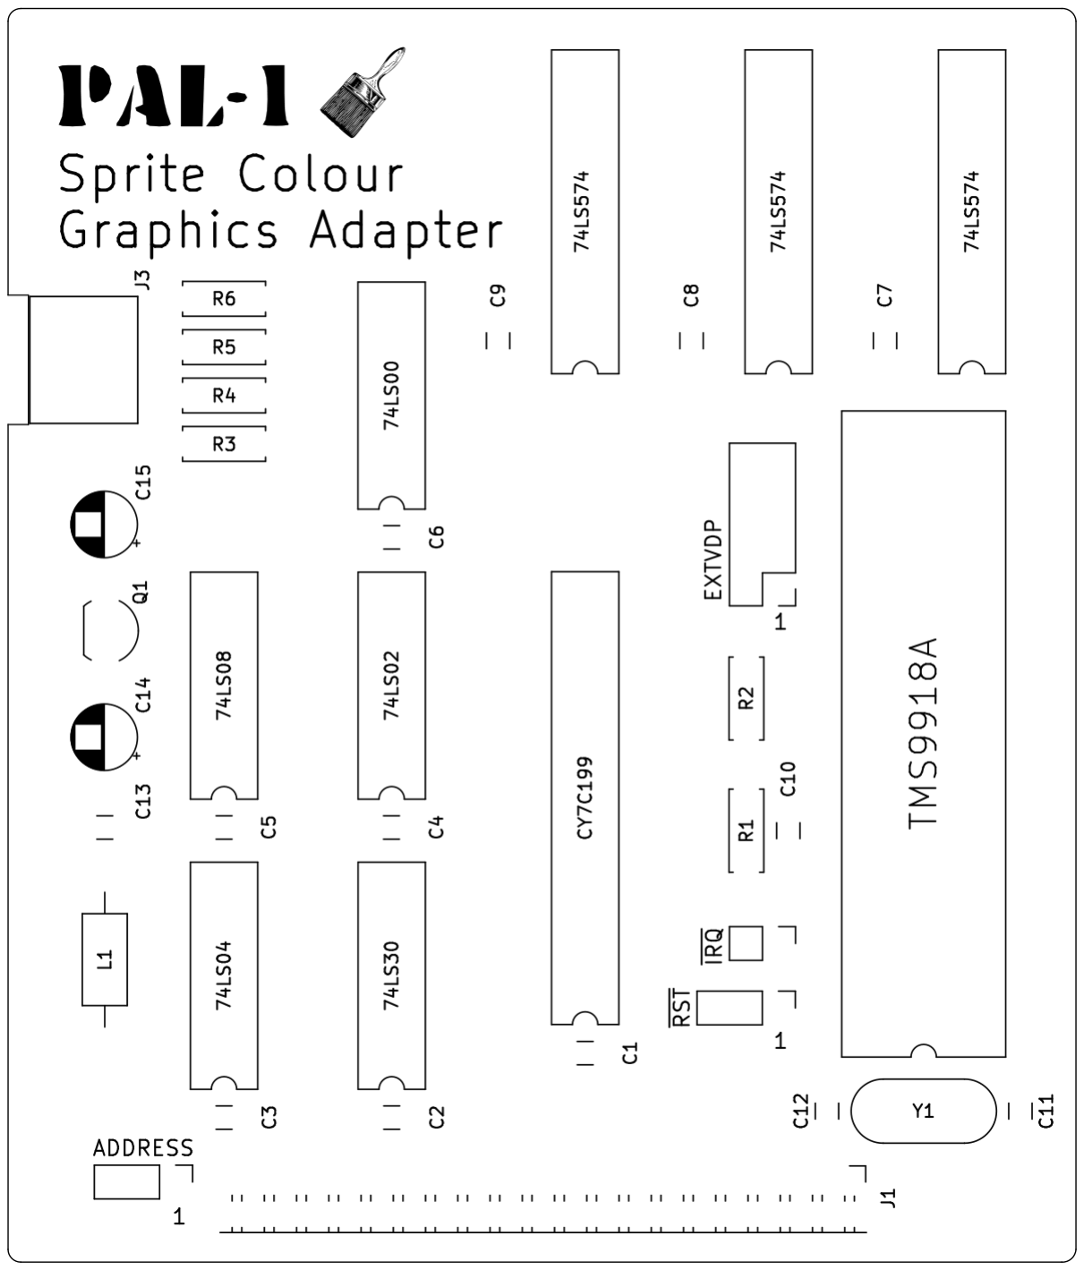
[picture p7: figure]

Figure C.1: PAL-1 Sprite Colour Graphics Adapter component locations.

13

14

# D. Bill of Materials

Part | Qty | Value | Description
C1 – C10, C13 | 11 | 0.1uF | Unpolarized capacitor
C11, C12 | 2 | 33pF | Unpolarized capacitor
C14 | 1 | 22uF | Polarized capacitor
C15 | 1 | 220uF | Polarized capacitor
J1 | 1 | Connector | Right angle connector, double row, 2x20
J2 | 1 | EXTVDP | Connetor, double row, 2x5
J3 | 1 | RCA | RCA jack
JP1 | 1 | /RST | Pin header, 1x3
JP2 | 1 | /IRQ | Pin header, 1x2
JP3 | 1 | ADDRESS | Pin header, 1x3
L1 | 1 | Inductor | Inductor, small bead
Q1 | 1 | 2N3904 | Small Signal NPN Transistor, TO-92
R1, R2 | 2 | 4K7 | Resistor, 250mA
R3 | 1 | 0 | Resistor, 250mA
R4 | 1 | 470 | Resistor, 250mA
R5, R6 | 2 | 75 | Resistor, 250mA
U1 | 1 | 74LS30 | 8-input NAND
U2 | 1 | 74LS00 | Quad 2-input NAND
U3 | 1 | 74LS02 | Quad 2-input NOR
U4 | 1 | 74LS04 | Hex Inverter
U5 | 1 | 74LS08 | Quad 2-input AND
U6 | 1 | TMS9918A | Video Display Processor
U7, U8, U9 | 3 | 74LS574 | 8-bit Register
U10 | 1 | CY7C199 | Static RAM, 32K x 8
Y1 | 1 | 10.7386Mhz | Two pin crystal

Table D.1: PAL-1 Sprite Colour Graphics Adapter v1.0A bill of materials.

15

16

# References

Ciarcia, Steve, ‘High-Resolution Sprite-Oriented Color Graphics’ (August 1982).

Ganning, Liu, ‘PAL-1 Microcomputer User Manual’ (November 2020), http://pal.aibs.ws/assets/PAL_en.pdf accessed 2024-08-18.

‘PAL-1 MOTHERBOARD’ (2021), http://pal.aibs.ws/assets/Motherboard_manual.pdf (http://pal.aibs.ws/assets/Motherboard_manual.pdf) accessed 2024-08-18.

LeMense, Tom, ‘SRAM Replacement for TMS99x8 VRAM’, Technical report (January 2010), https://retrobrewcomputers.org/n8vem-pbwiki-archive/0/35845334/48860720/33053543/SRAM%20Replacement%20for%20TMS99x8%20VRAM.pdf (https://retrobrewcomputers.org/n8vem-pbwiki-archive/0/35845334/48860720/33053543/SRAM%20Replacement%20for%20TMS99x8%20VRAM.pdf) accessed 2024-08-18.

Texas Instruments, ‘TMS9918A/TMS9928A/TMS9929A Video Display Processors’ (1982).

Werner, | Dan, | ‘Video | Display | Interface | Board’, | https://www.
retrobrewcomputers.org/doku.php?id=boards:ecb:scg: start (https://www.retrobrewcomputers.org/doku.php?id=boards:ecb:scg:start) accessed 2024-08-18.

17

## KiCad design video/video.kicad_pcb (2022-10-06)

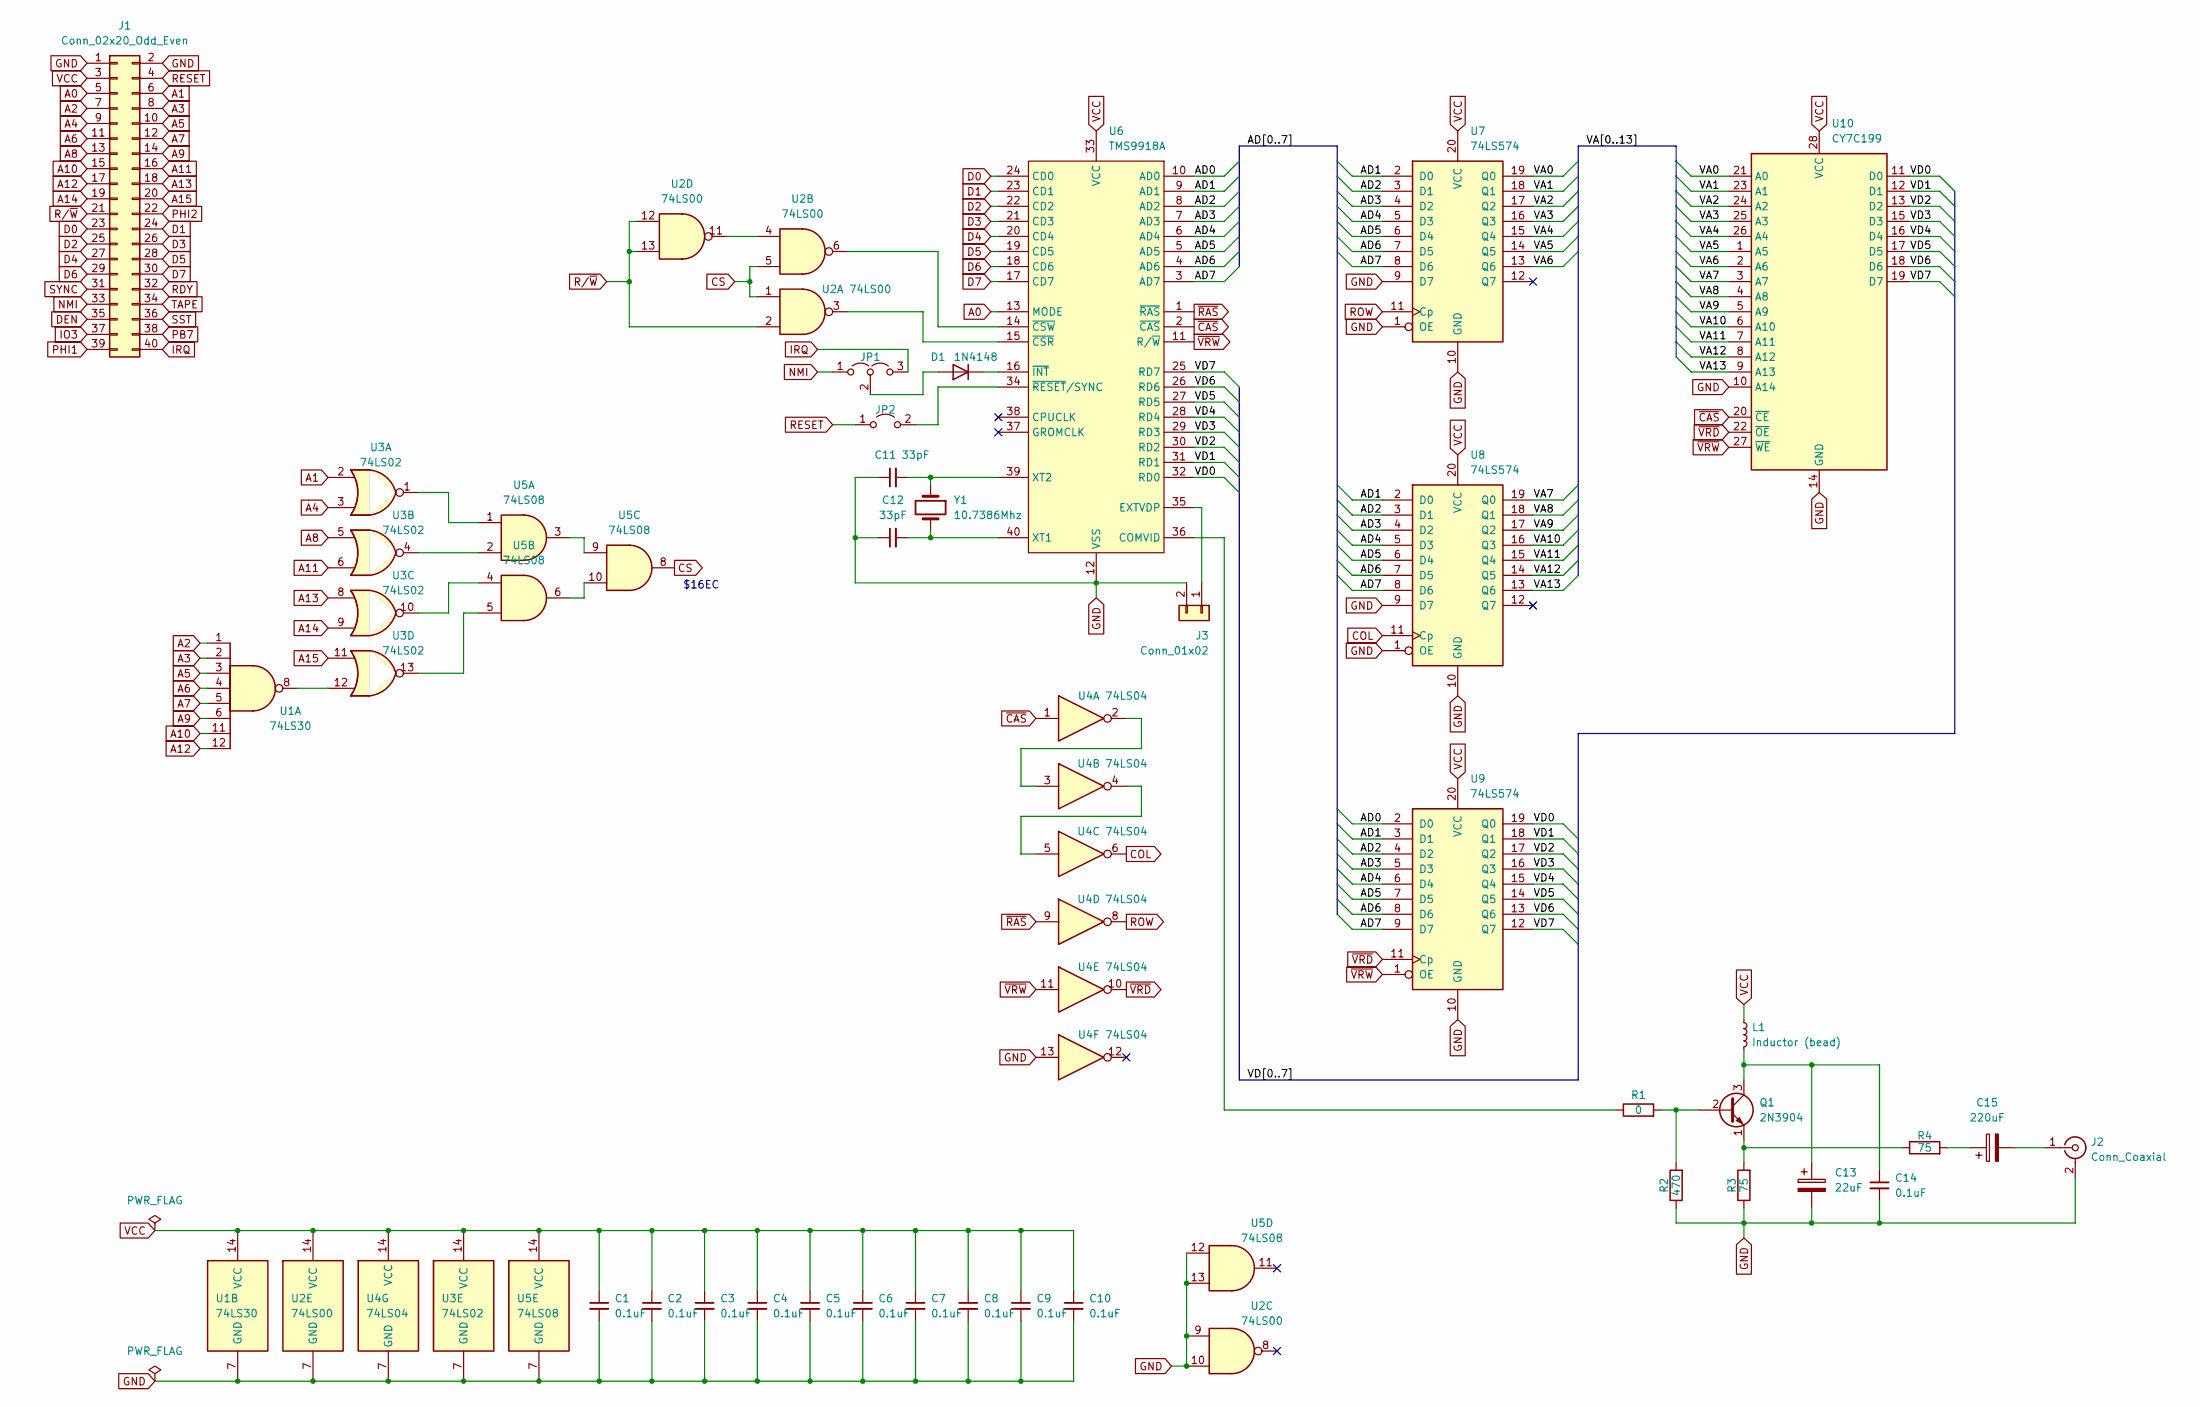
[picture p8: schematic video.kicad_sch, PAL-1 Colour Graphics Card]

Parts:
C1, C2, C3, C4, C5, C6, C7, C8, C9, C10, C14: 0.1uF; C_Disc_D3.0mm_W1.6mm_P2.50mm
C11, C12: 33pF; C_Disc_D4.7mm_W2.5mm_P5.00mm
C13: 22uF; CP_Radial_D5.0mm_P2.50mm
C15: 220uF; CP_Radial_D5.0mm_P2.50mm
D1: 1N4148; D_DO-35_SOD27_P7.62mm_Horizontal
J1: Conn_02x20_Odd_Even; PinHeader_2x20_P2.54mm_Vertical
J2: Conn_Coaxial; RCA right angle phono
J3: Conn_01x02; PinHeader_1x02_P2.54mm_Vertical
JP1: Jumper_3_Open; PinHeader_1x03_P2.54mm_Vertical
JP2: Jumper_2_Open; PinHeader_1x02_P2.54mm_Vertical
L1: Inductor (bead); L_Axial_L7.0mm_D3.3mm_P10.16mm_Horizontal_Fastron_MICC
Q1: 2N3904; TO-92_Inline
R1: 0; R_Axial_DIN0207_L6.3mm_D2.5mm_P7.62mm_Horizontal
R2: 470; R_Axial_DIN0207_L6.3mm_D2.5mm_P7.62mm_Horizontal
R3, R4: 75; R_Axial_DIN0207_L6.3mm_D2.5mm_P7.62mm_Horizontal
U1: 74LS30; DIP-14_W7.62mm
U2: 74LS00; DIP-14_W7.62mm
U3: 74LS02; DIP-14_W7.62mm
U4: 74LS04; DIP-14_W7.62mm
U5: 74LS08; DIP-14_W7.62mm
U6: TMS9918A; DIP-40_W15.24mm
U7, U8, U9: 74LS574; DIP-20_W7.62mm
U10: CY7C199; DIP-28_W7.62mm
Y1: 10.7386Mhz; Crystal_HC49-U_Vertical

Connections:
/AD0: U6.10 (AD0), U9.2 (D0)
/AD1: U6.9 (AD1), U7.2 (D0), U8.2 (D0), U9.3 (D1)
/AD2: U6.8 (AD2), U7.3 (D1), U8.3 (D1), U9.4 (D2)
/AD3: U6.7 (AD3), U7.4 (D2), U8.4 (D2), U9.5 (D3)
/AD4: U6.6 (AD4), U7.5 (D3), U8.5 (D3), U9.6 (D4)
/AD5: U6.5 (AD5), U7.6 (D4), U8.6 (D4), U9.7 (D5)
/AD6: U6.4 (AD6), U7.7 (D5), U8.7 (D5), U9.8 (D6)
/AD7: U6.3 (AD7), U7.8 (D6), U8.8 (D6), U9.9 (D7)
/VA0: U7.19 (Q0), U10.21 (A0)
/VA1: U7.18 (Q1), U10.23 (A1)
/VA2: U7.17 (Q2), U10.24 (A2)
/VA3: U7.16 (Q3), U10.25 (A3)
/VA4: U7.15 (Q4), U10.26 (A4)
/VA5: U7.14 (Q5), U10.1 (A5)
/VA6: U7.13 (Q6), U10.2 (A6)
/VA7: U8.19 (Q0), U10.3 (A7)
/VA8: U8.18 (Q1), U10.4 (A8)
/VA9: U8.17 (Q2), U10.5 (A9)
/VA10: U8.16 (Q3), U10.6 (A10)
/VA11: U8.15 (Q4), U10.7 (A11)
/VA12: U8.14 (Q5), U10.8 (A12)
/VA13: U8.13 (Q6), U10.9 (A13)
/VD0: U6.32 (RD0), U9.19 (Q0), U10.11 (D0)
/VD1: U6.31 (RD1), U9.18 (Q1), U10.12 (D1)
/VD2: U6.30 (RD2), U9.17 (Q2), U10.13 (D2)
/VD3: U6.29 (RD3), U9.16 (Q3), U10.15 (D3)
/VD4: U6.28 (RD4), U9.15 (Q4), U10.16 (D4)
/VD5: U6.27 (RD5), U9.14 (Q5), U10.17 (D5)
/VD6: U6.26 (RD6), U9.13 (Q6), U10.18 (D6)
/VD7: U6.25 (RD7), U9.12 (Q7), U10.19 (D7)
A0: J1.5, U6.13 (MODE)
A1: J1.6, U3.2
A2: J1.7, U1.1
A3: J1.8, U1.2
A4: J1.9, U3.3
A5: J1.10, U1.3
A6: J1.11, U1.4
A7: J1.12, U1.5
A8: J1.13, U3.5
A9: J1.14, U1.6
A10: J1.15, U1.11
A11: J1.16, U3.6
A12: J1.17, U1.12
A13: J1.18, U3.8
A14: J1.19, U3.9
A15: J1.20, U3.11
COL: U4.6, U8.11 (Cp)
CS: U2.1, U2.5, U5.8
D0: J1.23, U6.24 (CD0)
D1: J1.24, U6.23 (CD1)
D2: J1.25, U6.22 (CD2)
D3: J1.26, U6.21 (CD3)
D4: J1.27, U6.20 (CD4)
D5: J1.28, U6.19 (CD5)
D6: J1.29, U6.18 (CD6)
D7: J1.30, U6.17 (CD7)
DEN: J1.35
GND: C1.2, C2.2, C3.2, C4.2, C5.2, C6.2, C7.2, C8.2, C9.2, C10.2, C11.1, C12.1, C13.2, C14.2, J1.1, J1.2, J2.2 (Ext), J3.2, R2.1, R3.1, U1.7 (GND), U2.7 (GND), U2.9, U2.10, U3.7 (GND), U4.7 (GND), U4.13, U5.7 (GND), U5.12, U5.13, U6.12 (VSS), U7.1 (OE), U7.9 (D7), U7.10 (GND), U8.1 (OE), U8.9 (D7), U8.10 (GND), U9.10 (GND), U10.10 (A14), U10.14 (GND)
IO3: J1.37
IRQ: J1.40, JP1.3 (B)
NMI: J1.33, JP1.1 (A)
unnamed: C11.2, U6.39 (XT2), Y1.1
unnamed: C12.2, U6.40 (XT1), Y1.2
unnamed: C13.1, C14.1, L1.2, Q1.3 (C)
unnamed: C15.1, R4.2
unnamed: C15.2, J2.1 (In)
unnamed: D1.1 (K), U6.16 (~INT)
unnamed: D1.2 (A), JP1.2 (C)
unnamed: J3.1, U6.35 (EXTVDP)
unnamed: JP2.2 (B), U6.34 (~RESET/SYNC)
unnamed: Q1.1 (E), R3.2, R4.1
unnamed: Q1.2 (B), R1.2, R2.2
unnamed: R1.1, U6.36 (COMVID)
unnamed: U1.8, U3.12
unnamed: U2.3, U6.15 (~CSR)
unnamed: U2.6, U6.14 (~CSW)
unnamed: U2.4, U2.11
unnamed: U3.1, U5.1
unnamed: U3.4, U5.2
unnamed: U3.10, U5.4
unnamed: U3.13, U5.5
unnamed: U4.2, U4.3
unnamed: U4.4, U4.5
unnamed: U5.3, U5.9
unnamed: U5.6, U5.10
PB7: J1.38
PHI1: J1.39
PHI2: J1.22
RDY: J1.32
RESET: J1.4, JP2.1 (A)
ROW: U4.8, U7.11 (Cp)
R/~W: J1.21, U2.2, U2.12, U2.13
SST: J1.36
SYNC: J1.31
TAPE: J1.34
VCC: C1.1, C2.1, C3.1, C4.1, C5.1, C6.1, C7.1, C8.1, C9.1, C10.1, J1.3, L1.1, U1.14 (VCC), U2.14 (VCC), U3.14 (VCC), U4.14 (VCC), U5.14 (VCC), U6.33 (VCC), U7.20 (VCC), U8.20 (VCC), U9.20 (VCC), U10.28 (VCC)
~CAS: U4.1, U6.2 (~CAS), U10.20 (~CE)
~RAS: U4.9, U6.1 (~RAS)
~VRD: U4.10, U9.11 (Cp), U10.22 (~OE)
~VRW: U4.11, U6.11 (R/~W), U9.1 (OE), U10.27 (~WE)

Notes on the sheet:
$16EC

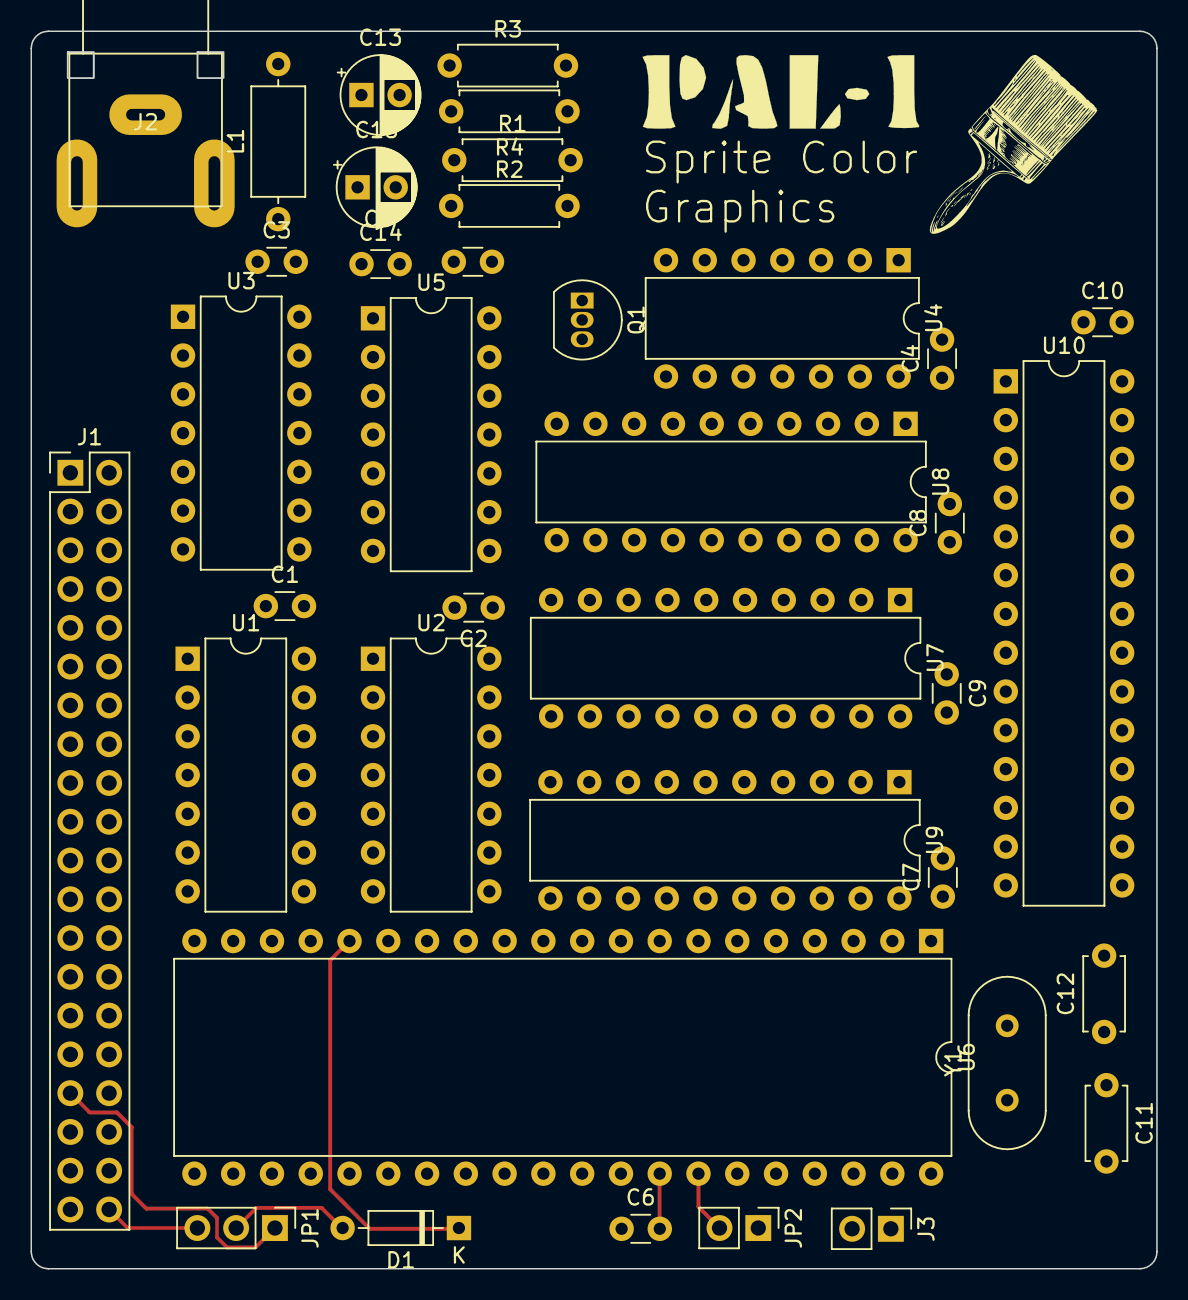
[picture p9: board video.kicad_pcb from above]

Board: 2 copper layers, 73.7 x 81.1 mm, 38 parts (0 on the bottom side), 90 nets.

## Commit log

2022-09-21 Initial version of schema
    [video.kicad_pcb, video.kicad_sch]
2022-10-06 Initial pcb layout
    [video.kicad_pcb, video.kicad_sch]
2024-08-23 Update appendixes
    [scga-bom-1.0a.csv]
2024-08-23 Update component descriptions
    [scga-bom-1.0a.csv]
